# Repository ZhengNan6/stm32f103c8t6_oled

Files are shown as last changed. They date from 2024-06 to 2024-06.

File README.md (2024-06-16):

# stm32f103c8t6_oled
基于stm32f103c8t6最小系统开发板
感谢嘉立创免费打板转接板
感谢实验室白嫖3D打印外壳

实现功能：
typeC口串口写入128×64像素图片，永久保存，可使用串口助手之类的去通信，但是我已经写了配套的exe程序，一键还挺方便的

有1.3寸oled显示屏和0.96寸oled显示屏两种版本，共用一份代码，使用时注意修改宏定义oled.h头文件中的OLED_SIZE宏定义

两者的区别可能是由于驱动芯片不一致，0.96寸的驱动芯片为ssd1306，1.3寸并不为这个，硬套用右侧会有白边，所以起始地址需要＋2

组装方法：
购买不焊接排针的stm32f103c8t6最小系统开发板，将排针朝上焊接
在PCB板上焊接oled屏幕，PCB转接板在有丝印的引脚焊接排母（尽量多，稳固）
通过排针排母实现整体硬件连接
再将3d打印外壳套上去就ok了

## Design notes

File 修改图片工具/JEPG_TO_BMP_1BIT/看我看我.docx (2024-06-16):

# 使用教程

使用前在window搜索“设备管理器”，查看有无设备

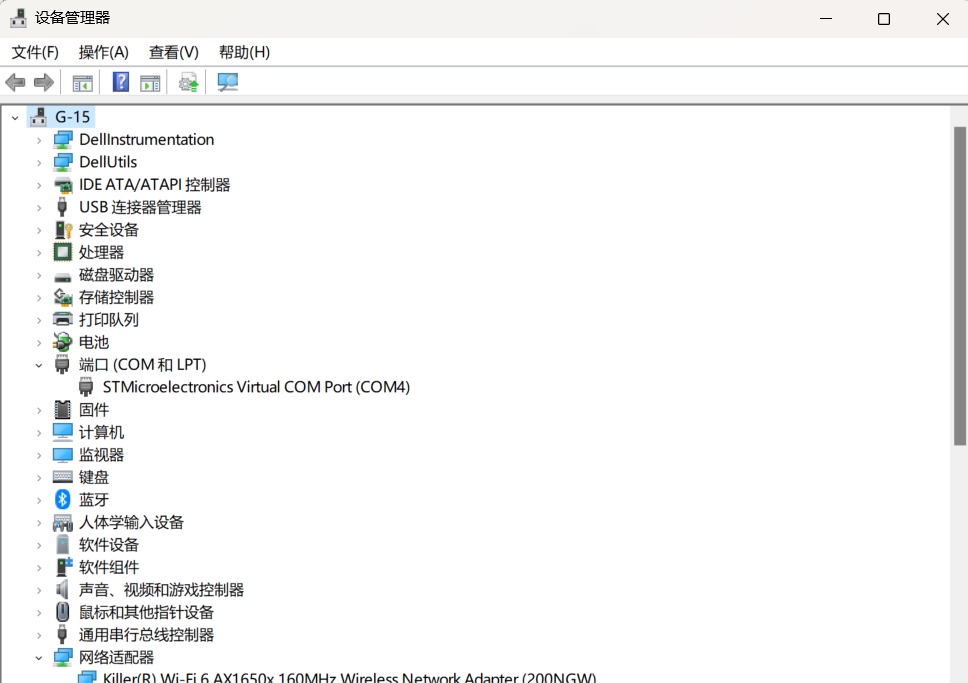
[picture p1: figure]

可以看到端口有一个“STM××巴拉巴拉”，就ok了，如果没有的话安装驱动，“en.stsw-stm32102_3”内的，选择对应版本，w11一般是不用安装驱动的。

BMP图片：

BMP图片需为长128宽64像素图片，深度需为1位，可以使用jpg图片转换，也可以手画

1 （若使用jpg图片）使用PS裁剪后转1位BMP 或 PS裁剪后运行文件夹内jpg_to_bmp.py，后者内置反相操作

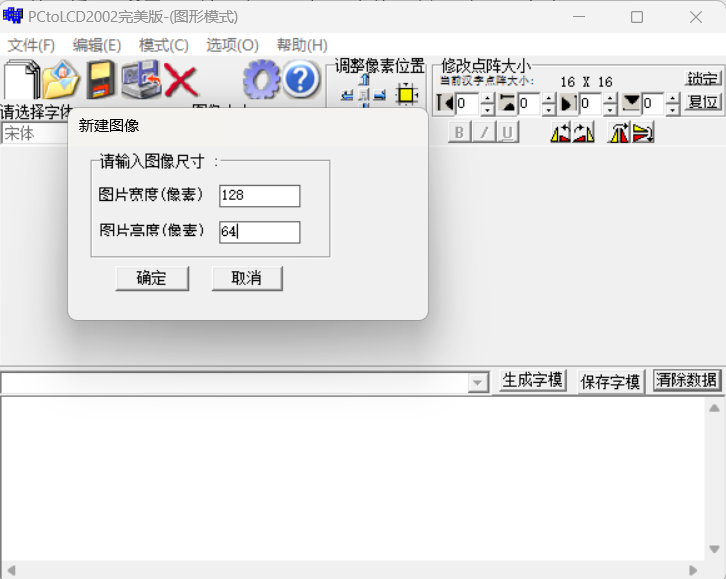
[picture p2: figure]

2 打开“取模软件”，打开“PCtoLCD2002.exe”
3 导入BMP图片

选择要的BMP图片，或者手画

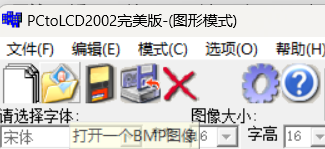
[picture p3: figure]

鼠标在板上绘画，绘画完后可导出为BMP图片，下次使用，或导出后进行反相操作（黑白颠倒，此步回到①）

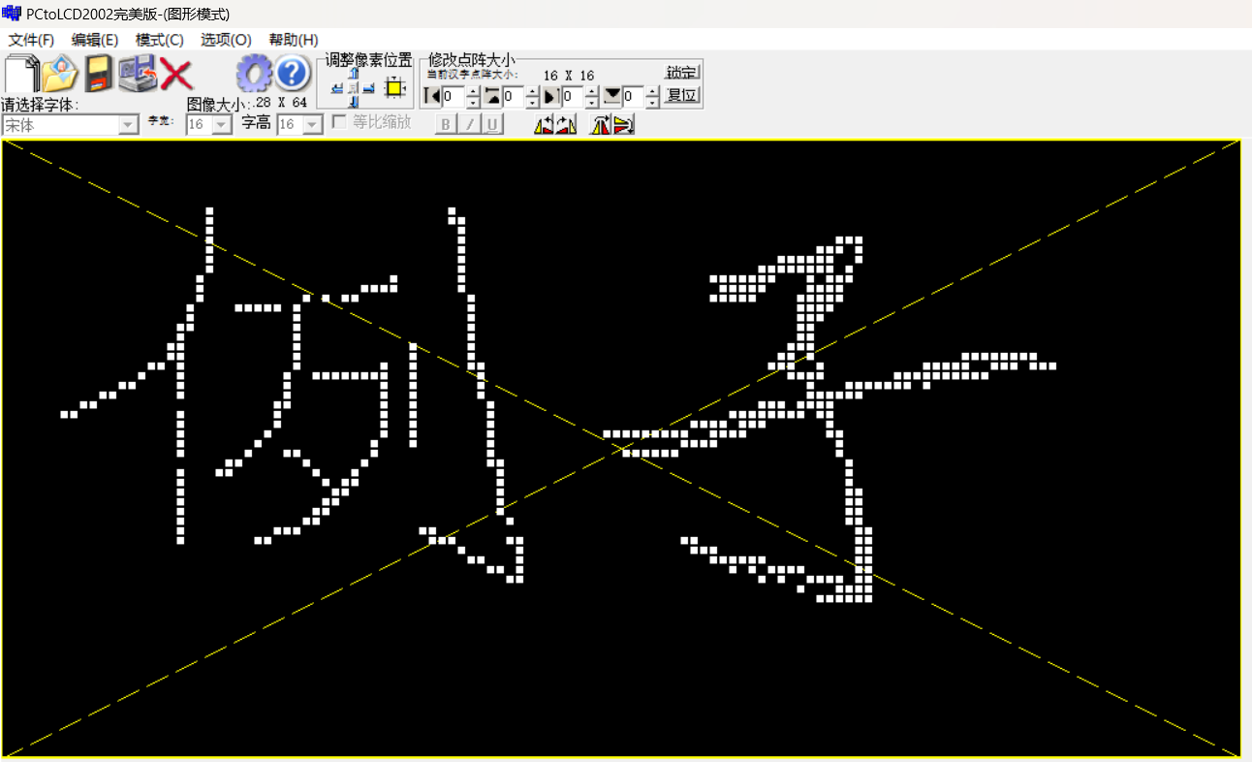
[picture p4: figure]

4 点击生成字模，从最开头的DB开始，到最后的;结束，复制，注意不要复制到后面的双引号

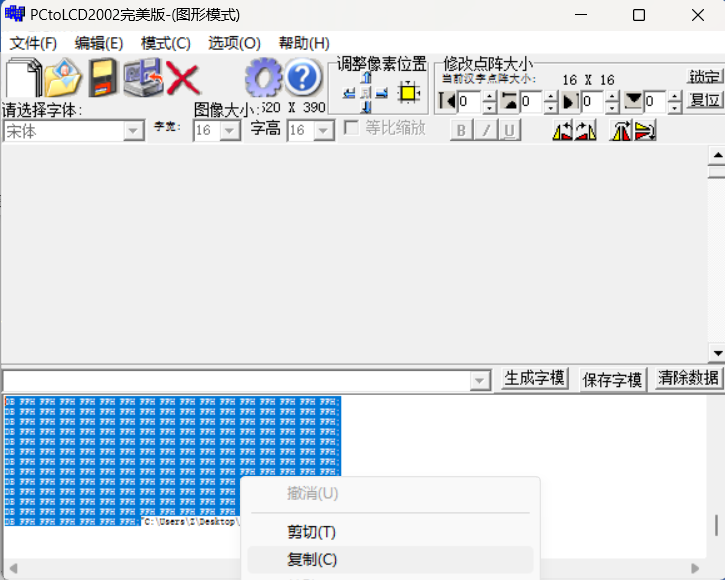
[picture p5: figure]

5 打开change_photo.exe，粘贴进去

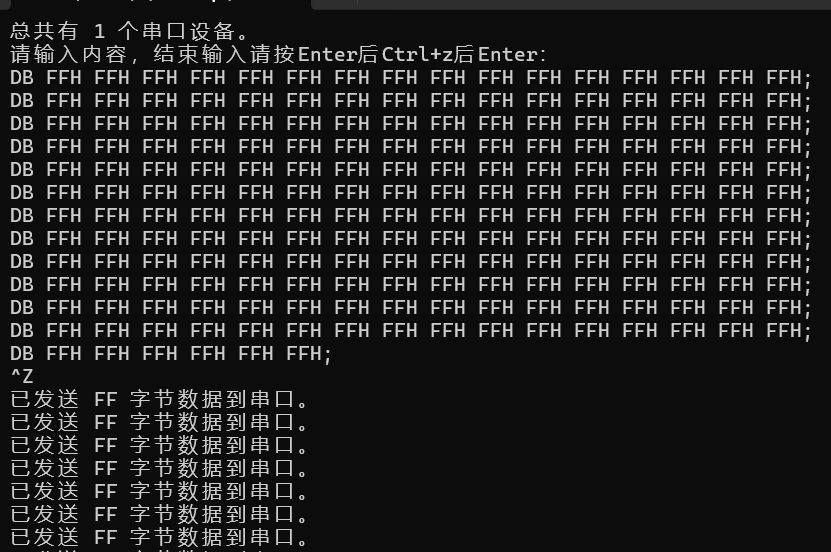
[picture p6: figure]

6 大功告成

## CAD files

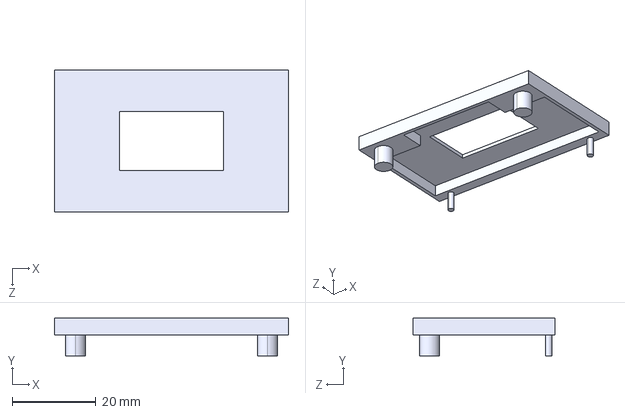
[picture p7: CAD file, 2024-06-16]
外壳建模/0.96OLED_3D/顶部盖板+2.4mmAND0.8mm圆柱插座.STEP
56.0 x 9.00 x 34.0 mm

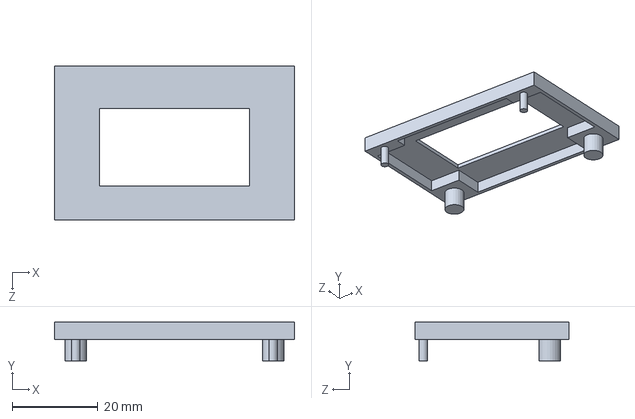
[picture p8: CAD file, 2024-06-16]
外壳建模/1.3OLED_3D/new顶.SLDPRT
56.0 x 9.00 x 36.0 mm

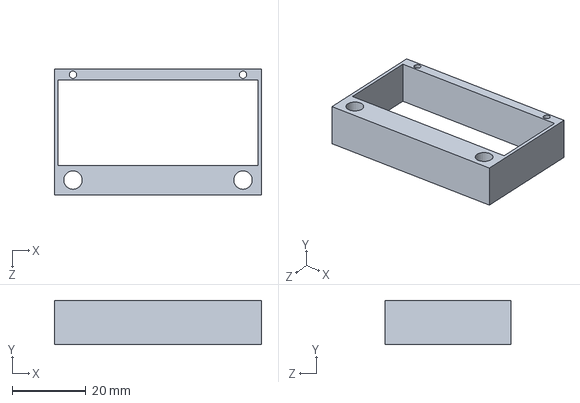
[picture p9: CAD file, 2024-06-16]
外壳建模/0.96OLED_3D/中部框体拓宽加定位槽.SLDPRT
56.0 x 12.0 x 34.0 mm

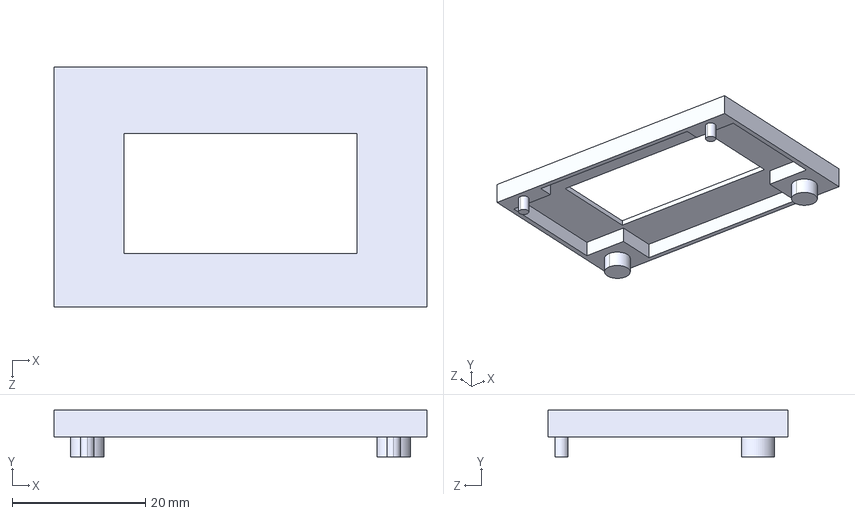
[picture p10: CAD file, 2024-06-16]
外壳建模/1.3OLED_3D/顶5mm2mm.STEP
56.0 x 7.00 x 36.0 mm

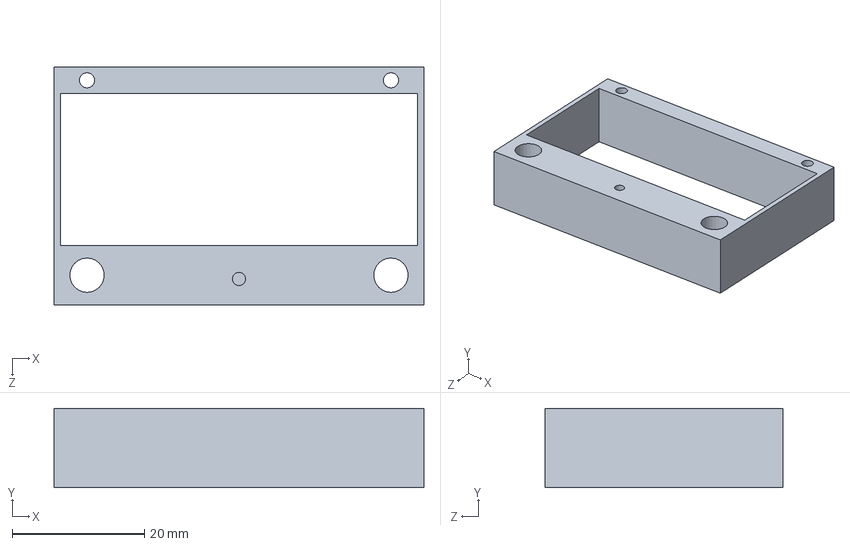
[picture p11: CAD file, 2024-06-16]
外壳建模/1.3OLED_3D/中部.SLDPRT
56.0 x 12.0 x 36.0 mm

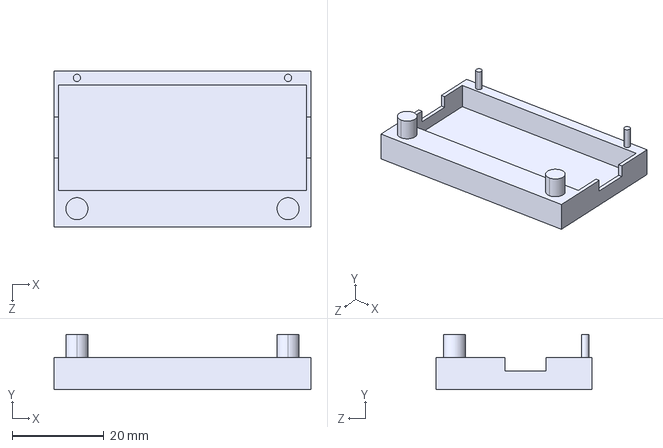
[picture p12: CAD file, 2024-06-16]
外壳建模/0.96OLED_3D/底盘+2.4mm0.8mm圆柱插座.STEP
56.0 x 12.0 x 34.0 mm

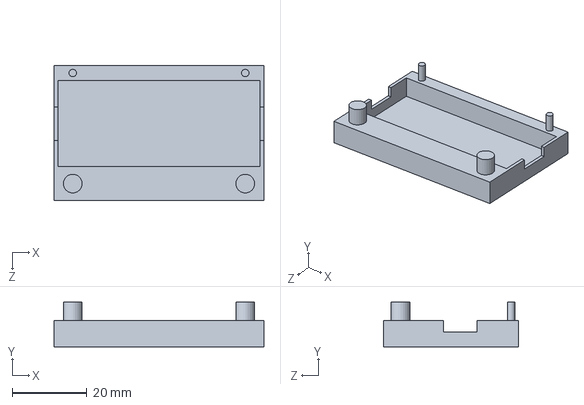
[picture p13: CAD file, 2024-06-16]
外壳建模/1.3OLED_3D/底部.SLDPRT
56.0 x 12.0 x 36.0 mm

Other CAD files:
外壳建模/0.96OLED_3D/中部框体+定位圆孔2.5mm1mm.STEP
外壳建模/1.3OLED_3D/中部5.2mm2.4mm.STEP
外壳建模/0.96OLED_3D/底盘+2.4mm圆柱插座.SLDPRT
外壳建模/0.96OLED_3D/顶部v3.0.SLDPRT
外壳建模/1.3OLED_3D/底部5mm2mm.STEP

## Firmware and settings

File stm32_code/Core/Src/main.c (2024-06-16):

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
/* Includes ------------------------------------------------------------------*/
#include "main.h"
#include "i2c.h"
#include "tim.h"
#include "usb_device.h"
#include "gpio.h"

/* USER CODE BEGIN Includes */
#include "oled.h"
#include "gui.h"
#include "bmp.h"
/* USER CODE END Includes */


void SystemClock_Config(void);
/* USER CODE BEGIN PFP */
void Write_BMP_Byte(uint8_t Byte);
/* USER CODE END PFP */

/* USER CODE BEGIN 0 */
#define BMP_Flash_SAVE  (0x08008000) //使用的地址，扇区32
//检查oled屏幕尺寸定义
#warning "记得检查在oled.h中的屏幕尺寸定义 check the oled size define in oled.h!!!!!!!!!!!!"
uint8_t BMP_Receive_Buff[1024] = {0};
uint64_t BMP_Receive_Byte_num = 0;
uint64_t BMP_Flash_Write_Byte_idx = 0;
uint64_t BMP_Flash_Need_Write_Byte = 0;//需写入flash的字节数

int BMP_Flash_Init(uint32_t Flash_Addr)
{
    //FLASH解锁
    HAL_FLASH_Unlock();
    __HAL_FLASH_CLEAR_FLAG(FLASH_FLAG_OPTVERR);
    
    //FLASH擦除
    FLASH_EraseInitTypeDef EraseInitStruct;
    EraseInitStruct.TypeErase = FLASH_TYPEERASE_PAGES;    //页擦除，一页为1kb，刚好储存一张128*64像素图片
    EraseInitStruct.PageAddress = Flash_Addr;    //页地址
    EraseInitStruct.NbPages = 1;    //擦除多少个页
    uint32_t PageError = 0;            //记录擦除出错时的起始地址
    if(HAL_FLASHEx_Erase(&EraseInitStruct, &PageError)!=HAL_OK)
    {
        return 0;
    }
    //FLASH上锁
    HAL_FLASH_Lock();    
    return 1;
}


int Flash_HAL_Write_N_2Byte_Data(uint32_t Write_addr, uint8_t *data, uint16_t num)
{
    //1、FLASH解锁
    HAL_FLASH_Unlock();
    __HAL_FLASH_CLEAR_FLAG(FLASH_FLAG_OPTVERR);
    
//    //2、FLASH擦除
//    FLASH_EraseInitTypeDef EraseInitStruct;
//    EraseInitStruct.TypeErase = FLASH_TYPEERASE_PAGES;    //页擦除
//    EraseInitStruct.PageAddress = BMP_Flash_SAVE;    //从第几个页开始擦除（0开始）
//    EraseInitStruct.NbPages = 1;    //擦除多少个页
//    uint32_t PageError = 0;            //记录擦除出错时的起始地址
//    if(HAL_FLASHEx_Erase(&EraseInitStruct, &PageError)!=HAL_OK)
//    {
////        printf("FLASH擦除出错,开始出错地址:%#x\r\n", PageError);
//        return -1;
//    }
    //3、FLASH写入
    for(uint16_t i=0; i<num; i++)
    {
        uint16_t Write_Data = (data[i*2+1] << 8 | data[i*2]);
        if(HAL_FLASH_Program(TYPEPROGRAM_HALFWORD, Write_addr, Write_Data)!=HAL_OK)
        {
//            printf("FLASH写入失败\r\n");
            return -1;
        }
        Write_addr += sizeof(uint16_t);
    }
    //4、FLASH上锁
    HAL_FLASH_Lock();    
    return 0;
}


void Write_BMP_Byte(uint8_t Byte)
{
    static uint16_t Flash_write_time = 0;
}
        uint64_t Write_2Byte_num;
/* USER CODE END 0 */

/**
  * @brief  The application entry point.
  * @retval int
  */
int main(void)
{
  /* MCU Configuration--------------------------------------------------------*/

  /* Reset of all peripherals, Initializes the Flash interface and the Systick. */
  HAL_Init();

  /* Configure the system clock */
  SystemClock_Config();

  /* Initialize all configured peripherals */
  MX_GPIO_Init();
  MX_I2C1_Init();
  MX_TIM1_Init();
  MX_USB_DEVICE_Init();
  /* USER CODE BEGIN 2 */
  OLED_Init();			         //初始化OLED  
  OLED_Clear(0);             //清屏（全黑）
  memcpy(BMP_Receive_Buff, (uint8_t*)BMP_Flash_SAVE, 1024); //从flash中搬运历史图片
  /* USER CODE END 2 */

  /* Infinite loop */
  /* USER CODE BEGIN WHILE */
  while (1)
  {
    /* USER CODE END WHILE */
      //开机后首次接收到图片信息 或 接收完一整幅图片后再接收到图片 时刷新flash空间
    if (BMP_Flash_Need_Write_Byte > 1 && BMP_Flash_Write_Byte_idx == 0)
        BMP_Flash_Init(BMP_Flash_SAVE);
    
    if (BMP_Flash_Need_Write_Byte >= 2)//由于flash的写入是以2字节为最小单位，所以每有大于或等于两个字节再写入flash
    {
        //uint64_t Write_2Byte_num;
        if (BMP_Flash_Write_Byte_idx + BMP_Flash_Need_Write_Byte > 1023)
        {   //接收完一整幅图片，把上一副图片剩余部分全写入flash,剩下新的图片下次循环再写入
            Write_2Byte_num = (1024-BMP_Flash_Write_Byte_idx)/2;   
        }
        else
        {
            Write_2Byte_num = BMP_Flash_Need_Write_Byte/2;
        }
        //写入图片flash
        Flash_HAL_Write_N_2Byte_Data(BMP_Flash_SAVE+BMP_Flash_Write_Byte_idx*sizeof(uint8_t), 
                                     BMP_Receive_Buff+BMP_Flash_Write_Byte_idx,
                                     Write_2Byte_num);
                                    
        BMP_Flash_Write_Byte_idx += Write_2Byte_num*2;
        BMP_Flash_Write_Byte_idx = BMP_Flash_Write_Byte_idx%1024;
        
        BMP_Flash_Need_Write_Byte -= Write_2Byte_num*2;
    }
    
    GUI_DrawBMP(0, 0, 128, 64, BMP_Receive_Buff, 1);
    /* USER CODE BEGIN 3 */
  }
  /* USER CODE END 3 */
}

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


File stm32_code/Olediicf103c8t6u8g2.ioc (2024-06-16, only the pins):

Mcu.UserName=STM32F103C8Tx
PA11.Signal=USB_DM
PA12.Signal=USB_DP
PA13.Signal=SYS_JTMS-SWDIO
PA14.Signal=SYS_JTCK-SWCLK
PB6.Signal=I2C1_SCL
PB7.Signal=I2C1_SDA
PD0-OSC_IN.Signal=RCC_OSC_IN
PD1-OSC_OUT.Signal=RCC_OSC_OUT

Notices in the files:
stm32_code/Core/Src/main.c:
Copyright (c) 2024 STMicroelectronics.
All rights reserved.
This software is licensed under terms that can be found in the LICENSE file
